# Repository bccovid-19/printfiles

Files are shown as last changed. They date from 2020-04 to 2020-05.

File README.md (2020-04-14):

# BC Covid-19 3D Printing Effort #

Hello,

If you are reading this it means you are thinking of helping the COVID-19 fight with your 3D printer. That's great! Please see more information below.

## How to start contributing? ##

The following questions are extracted from the [BC Covid-19 3D Printing Effort Starting Guide](https://docs.google.com/document/d/1Ttu-DrwoGttRoviB6C2idflY3-9sC5mBmkxYlhFMHls/edit?usp=sharing). This file is being kept up-to-date by our community and you will find the latest information there.

## Who's organizing all this? ##

Currently we are getting organized using the [BC Covid-19 3D Printing Slack channel](https://join.slack.com/t/bccovid-19/shared_invite/zt-cz01ettu-XZs6dWzob92pDKfFyCusag). There you can find the latest information on our efforts.

## How can I help? ##

- First you should sign up as a supplier using this [form](https://sites.google.com/view/gvrd-face-shield-printers/home/headset-printers).
- Check the demand for the items [here](https://sites.google.com/view/gvrd-face-shield-printers/home/total-supply-and-demand?authuser=0).
- Download the `.stl` files in this repo. Those are the files being used by our community.

## Is there a specific item in high demand? ##

Both [Visor Frames](https://github.com/bccovid-19/printfiles/tree/master/3DV%20Visor%20Frame) and [Ear Savers](https://github.com/bccovid-19/printfiles/tree/master/Ear%20Saver) are needed. You can check the current demand for the items [here](https://sites.google.com/view/gvrd-face-shield-printers/home/total-supply-and-demand?authuser=0).

## What 3D printers are required, known to work, or recommended? ##

Visor frames measure 159x193mm so printers must have plates large enough. If your build plate is too small, you may still be able to contribute with the Ear Savers. Beyond this any FDM printer should work.

## Am I required to print with a specific filament type? ##

- For both visor frames and ear savers, *PETG is preferred but PLA is acceptable.*

## Are there any specific slicing configurations needed (layer height, printing speed, etc.)? ##

Please take some time to read [this guide](https://3dverkstan.se/protective-visor/protective-visor-print-guide/), since it has some good information that can even speed up the printing time. Also see the Readme for each model.

## I have a few items printed, what now? ##

Delivery is likely to be handled by a local company, as will most pick-ups (more details expected by April 1st, 2020). We'll ask that each producer withhold the items they've printed for collection when there's a decent amount available, rather than a few at a time.

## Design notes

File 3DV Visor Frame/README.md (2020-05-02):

# 3DV Visor Frames

Please see http://faceshield.nu for information.
- [Print Settings Guide](https://3dverkstan.se/protective-visor/protective-visor-print-guide/)
- [Packaging & Handling](http://translate.google.com/translate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), specific to Sweden, but useful nonetheless.

# Common/Recommended Print Settings (See Print Settings Guide above for further details)
- Material: PETG, PLA acceptable if no other choice
- Nozzle: 0.4 mm (most common) to 1.0 mm
- Extrusion Width (0.4 mm to 0.6 mm nozzle, preferred): 0.72 mm
- Extrusion Width (0.4 mm to 0.6 mm nozzle, alternate): 0.70 mm, or see the guide.
- Extrusion Width (0.8 mm to 1.0 mm nozzle): 1.0 mm
- Layer Height: ~0.3 mm
- Infill: 0%, or increase to 100% if nubs have holes in them
- Walls: 3-4, goal is to have solid fill, i.e. the arms should be only filled with perimeters
- Support: No (N/A)
- Note that these are relatively aggressive print settings, may not work with all printers and will likely require finetuning. Your hotend's maximum volumetric flow (a factor of your extrusion width, layer height, and print speed) will likely determine how fast you can print each visor frame. For most printers, between 9-25 minutes/frame is very reasonable. You may need to run your extruder temperature hotter than normal to maintain good flow.
- For anyone new to printing PETG, main points to remember compared to PLA, it needs a hotter extruder temperature (220-260C), hotter build plate (70-100C), and is prone to stringing. Consider enabling "Combing" (print head avoids crossing perimeters) or equivalent, and especially with bowden setups, pay attention to retraction distance, retraction speed, and travel speed.

# File Selection
The [Extended Visor](./bcc3d_extended_v5.stl) version is preferred due to the increased forehead clearance and comfort. If your build plate cannot fit this model, then the standard [0.6mm Version](./Visor_Frame_NORTH_AMERICA_letter_6-hole_v5-0.6mm_chamferred.stl) and  [1mm Version](./Visor_Frame_NORTH_AMERICA_letter_6-hole_v5-1mm_chamferred.stl) are acceptable.

# Standard Visor
The [0.6mm Version](./Visor_Frame_NORTH_AMERICA_letter_6-hole_v5-0.6mm_chamferred.stl) should be tried first, as it has a reduced print time. If this version adheres too much to your print bed and is unable to be removed without damage please switch to the [1mm Version](./Visor_Frame_NORTH_AMERICA_letter_6-hole_v5-1mm_chamferred.stl).

# Extended Visor
The [Extended Visor](./bcc3d_extended_v5.stl) version can be used for practitioners needing an extended space between the visor and the face to accommodate glasses or goggles. It also increases the width of of the forehead contact surface and permits the use of padding (weatherstripping foam) if desired. It has been confirmed to work with the same dimensions and hole pattern as the standard version.

# Files for Prusa MK3 and MK3s

Within the `For Prusa MK3 and MK3s` folder you will find two .3mf files. These are print profiles of the [Extended Visor](./bcc3d_extended_v5.stl), with relatively aggressive settings for quick prints. One has had the bands flipped to spread the wear on the build platform a bit better.

# Credits

- 3D-Printed Protective Visor by 3DVerkstan/Erik Cederberg https://www.youmagine.com/designs/protective-visor-by-3dverkstan/
- 3D Printed Face Shield by by Retrolabs (remix of 3DVerkstan's model) https://retrolabs.com/3d-prints/3d-printed-face-shield-with-10-mil-pvc

# Changelog

### Version 5 - Extended:

- V5 provided by 3DVerskstan remixed with Retrolab's "Closed Top Padded" version

### Version 5:

- V5 provided by 3DVerskstan (improved joint between arms and forehead section, added separate file for 1 mm thick section)
- Chamfer added on the upper edges

### Version 3.3:

- Remixed to add chamfer on the upper edges

### Version 3:

- Original North America 6-hole version provided by 3DVerkstan

# License
This remix is created under [Creative Commons Attribution Share Alike](https://creativecommons.org/licenses/by-sa/3.0/deed.en_US)
- Commercial use is allowed, you must attribute the creator, you may remix this work and the remixed work should be made available under this license.

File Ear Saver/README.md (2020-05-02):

# ES.V4: ear_saver_small_V004.STL

## Recommended print settings

- Material: *PETG is preferred, PLA is acceptable*
- Nozzle: 0.4 mm to 1.0 mm
- Extrusion width (0.4 mm to 0.6 mm nozzle, preferred): 0.72 mm
- Extrusion width (0.4 mm to 0.6 mm nozzle, alternate): any divisor of 3.5 mm (eg. 0.5 mm, 0.583 mm, 0.7 mm, 0.875 mm)
- Extrusion width (0.8 mm to 1.0 mm nozzle): 1.44 mm
- Initial layer height: !!! This must be 0.3 mm
- Layer height: !!! This must be 0.3 mm
- Infill: N/A - Thin enough that it should print solid
- Walls: 3-4 for extrusion width of 0.72 mm; 2-3 for extrusion width of 1.44 mm; 5 for thinner extrusion widths
- Support: No (N/A)
- Note that these are relatively aggressive print settings, may not work with all printers and will likely require finetuning. Your hotend's maximum volumetric flow (a factor of your extrusion width, layer height, and print speed) will likely determine how fast you can print each ear saver. For most printers, between 3-10 minutes/ear saver is very reasonable. You may need to run your extruder temperature hotter than normal to maintain good flow.
- For anyone new to printing PETG, main points to remember compared to PLA, it needs a hotter extruder temperature (220-260C), hotter build plate (70-100C), and is prone to stringing. Consider enabling "Combing" (print head avoids crossing perimeters) or equivalent, and especially with bowden setups, pay attention to retraction distance, retraction speed, and travel speed.

## Documentation
[Google Document Link](https://docs.google.com/document/d/15-V81oS8I5RemRSrTbresdDm_2dw-AZuGhGRkiqIBxc)

## Credits

- Surgical mask strap by marslam on Thingiverse: https://www.thingiverse.com/thing:4202906
- surgical_mask_strap_small - Remix v03 for small beds by Crowshank on Thingiverse: https://www.thingiverse.com/thing:4246836
- Covid Surgical Mask Strap (ear_saver_small_V004) on Thingiverse: https://www.thingiverse.com/thing:4251451

## Changelog

### Version 4:

- Optimized layer and tool-path, prints with 0.3 mm layer height and 0.72 mm line width
- Added ergonomic centre design, reduced total material usage
- Changed angle of hooks for less tangling in hair, and better mask retention
- Reduced overall height to improve nesting
- Added step-over to improve layer bonding and create a rounded surface for handling

### Version 3:

- Overall length reduced to fit on smaller print beds
- Hook shape adjusted to improve printability
- Overall height scaled to reduce thickness of strap and hooks (improved flexibility and reduced print time)

## License
CC-BY 4.0 https://creativecommons.org/licenses/by/4.0/

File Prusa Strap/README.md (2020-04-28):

# Strap for Prusa RC3 Visor Frame and variants
This is a strap remix for the Prusa RC3 visor frame and BCC3D injection molded visor frame. Intended to be used with PETG only. Print this model only if requested.

## Details
- Material: PETG
- Extrusion/Line Width: 0.5 mm
- Layer Height: 0.2 mm

## Credits
- TPU Strap for the Prusa Protective Shield by Neil-Seattle https://www.prusaprinters.org/prints/27615-tpu-strap-for-the-prusa-protective-shield
- PETG Strap for the Prusa Protective Shield by Mike B https://www.prusaprinters.org/prints/28667-petg-strap-for-the-prusa-protective-shield

## License
This remix is created under [Attribution-ShareAlike 4.0 International (CC BY-SA 4.0)](https://creativecommons.org/licenses/by-sa/4.0/)

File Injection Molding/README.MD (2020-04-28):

# Injection Molded Frames

These are a near-complete version of what is being used by BC Covid-19 3D Printing Group for injection molding of a modified Prusa Face Shield. This mold was developed by [Cypress Solutions](http://www.cypress.bc.ca/), one of our generous sponsors, incorporating feedback from BC Covid-19.

Cypress Logo

# Credits
Prusa Face Shield by Prusa Research https://www.prusaprinters.org/prints/25857

# License
This remix is created under [Attribution-NonCommercial 4.0 International (CC BY-NC 4.0)](https://creativecommons.org/licenses/by-nc/4.0/)

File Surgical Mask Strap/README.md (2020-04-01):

# MS.V3: surgical_mask_strap_small_V003_Z60%_Single

## Recommended print settings
 - Material: PLA
 - Nozzle: 0.4 mm
 - Quality: Draft (0.3 - 0.35 mm)
 - Infill: N/A - Thin enough that it should print solid
 - Walls: 2
 - Support: No (N/A)

## Documentation
[Google Document Link](https://docs.google.com/document/d/15-V81oS8I5RemRSrTbresdDm_2dw-AZuGhGRkiqIBxc)

## Credits

 - Surgical mask strap by marslam on Thingiverse: https://www.thingiverse.com/thing:4202906
 - surgical_mask_strap_small - Remix v03 for small beds by Crowshank on Thingiverse: https://www.thingiverse.com/thing:4246836

## Changes

 - overall length reduced to fit on smaller print beds
 - hook shape adjusted to improve printability
 - overall height scaled to reduced thickness of strap and hooks (improved flexibility and reduced print time)

## License
CC-BY 4.0 https://creativecommons.org/licenses/by/4.0/

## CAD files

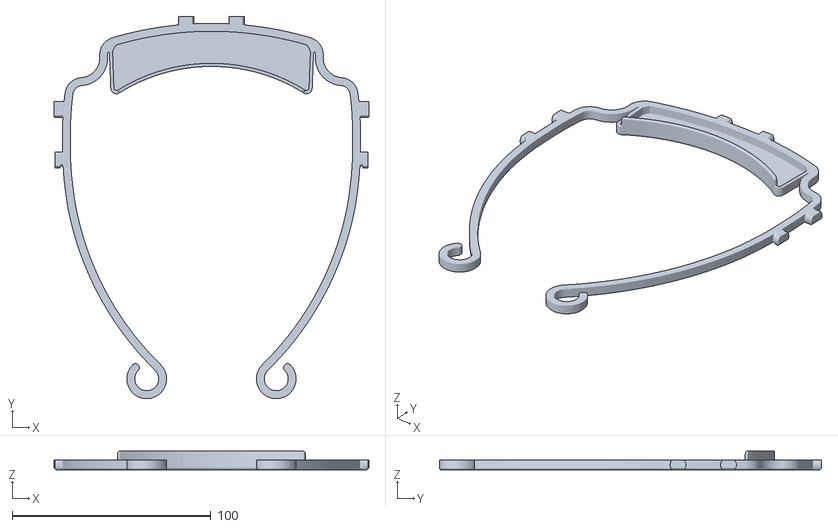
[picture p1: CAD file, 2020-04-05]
3DV Visor Frame/bcc3d_extended_v5.stl
158.5 x 192.4 x 9.56

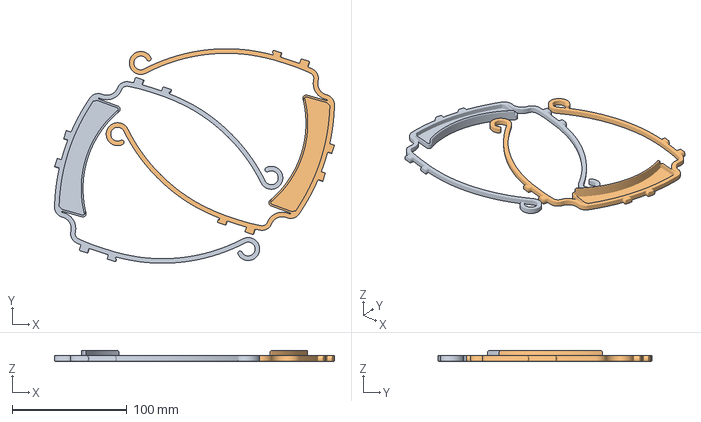
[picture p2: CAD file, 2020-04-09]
3DV Visor Frame/For Prusa i3 MK3 and MK3s/3DVerkstan_RetroLabs_v5_padded_NA_6hole_x2.3mf
243.7 x 186.6 x 9.56 mm
3DVerkstan_RetroLabs_v5_padded_NA_6hole.stl x 2

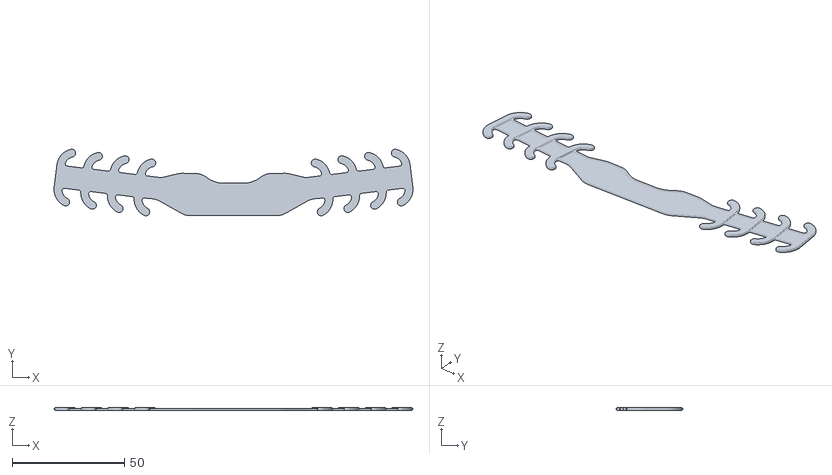
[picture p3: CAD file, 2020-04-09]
Ear Saver/ear_saver_small_V004.STL
160.2 x 29.7 x 1.20

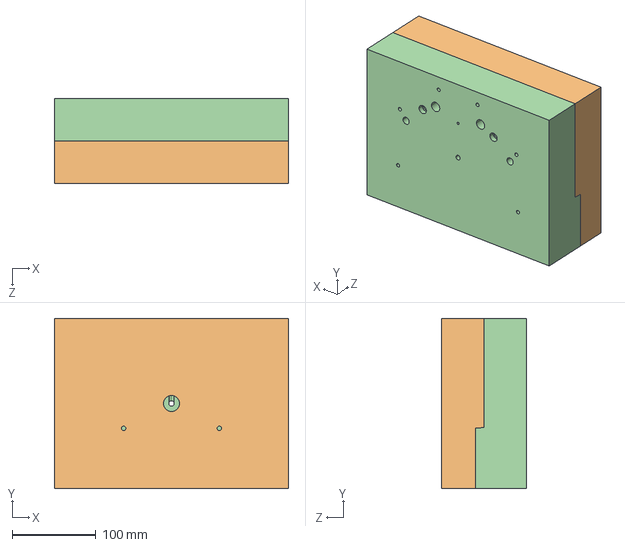
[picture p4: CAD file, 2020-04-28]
Injection Molding/cypress_face_shield_frame-v3.STEP
279.4 x 203.2 x 101.6 mm

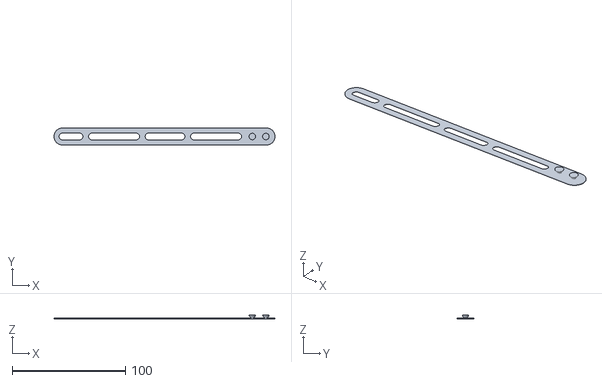
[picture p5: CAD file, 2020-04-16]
Prusa Strap/BCC3D_PETG_Prusa_Strap.4-pin.stl
195.0 x 15.0 x 3.49

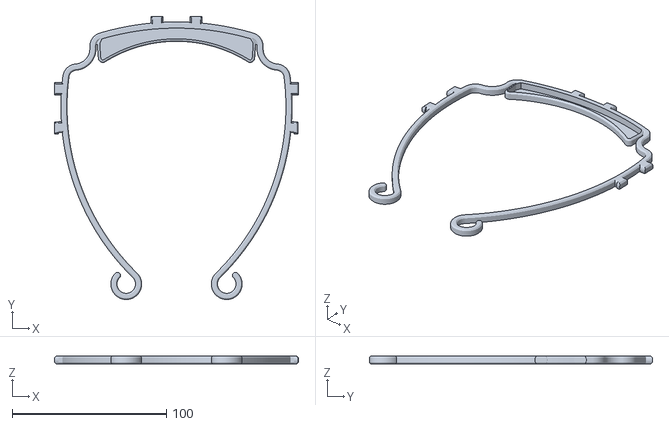
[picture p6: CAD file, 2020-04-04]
3DV Visor Frame/Visor_Frame_NORTH_AMERICA_letter_6-hole_v5-0.6mm_chamferred.stl
158.5 x 183.6 x 5.00

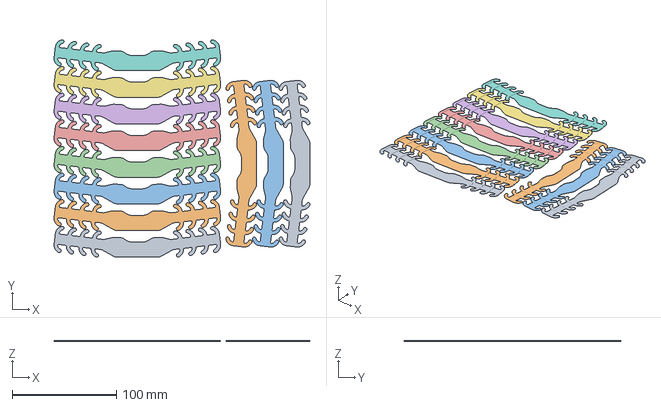
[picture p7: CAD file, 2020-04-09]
Ear Saver/ear_saver_small_V004_11x_prusa_PETG.3mf
245.9 x 208.9 x 1.20 mm

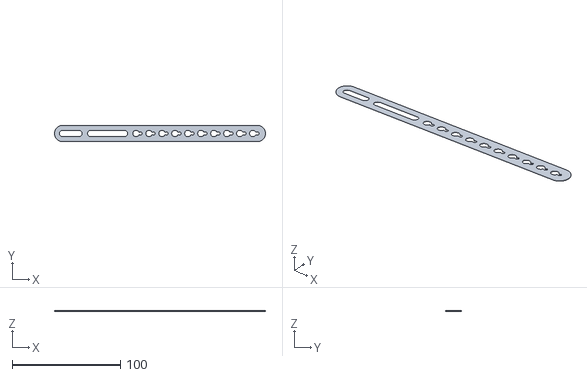
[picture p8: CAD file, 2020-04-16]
Prusa Strap/BCC3D_PETG_Prusa_Strap.4-hole.stl
195.0 x 15.0 x 0.8

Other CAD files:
3DV Visor Frame/For Prusa i3 MK3 and MK3s/3DVerkstan_RetroLabs_v5_padded_NA_6hole_x2 (flipped).3mf
3DV Visor Frame/Visor_Frame_NORTH_AMERICA_letter_6-hole_v5-1mm_chamferred.stl
Injection Molding/cypress_face_shield_frame-v3.x_t

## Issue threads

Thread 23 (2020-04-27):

The Slack Invite Link has expired

linderr, 2020-04-27:
Hi! My name is Linda and I am from www.findthemasks.ca
I spoke on the phone with Petko to join the Slack group but your link has already expired on both your main website as well as the README file on GitHub.

Please share or update a Slack link - thank you!

dan-bcc3d, 2020-04-28:
Hi linderr,

This has been fixed in https://github.com/bccovid-19/track/commit/aeb433f5ef4bd49216f60c0f2c8a6f111b863b31

Regards,
Dan

Closed 2020-04-28.

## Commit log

2020-03-31 added 3dv north america visor frame
    [Visor_Frame_NORTH_AMERICA_letter_6-hole_v3.stl]
2020-03-31 added links to print & packaging guides
2020-03-31 replace 3dv visor with chamferred version
    [Visor_Frame_NORTH_AMERICA_LETTER_v3.3.stl, Visor_Frame_NORTH_AMERICA_letter_6-hole_v3.stl]
2020-04-01 added pruse rc3 face shield
    [covid19_headband_rc3_3dvnubsBCStandard.v.5.stl, covid19_headband_rc3_3dvnubsHexadic.v.5.stl]
2020-04-01 removed prusa design
    - as it's causing confusion about what to print
    [covid19_headband_rc3_3dvnubsBCStandard.v.5.stl, covid19_headband_rc3_3dvnubsHexadic.v.5.stl]
2020-04-04 Update to V5 chamferred version of files.
    [Visor_Frame_NORTH_AMERICA_letter_6-hole_v5-0.6mm_chamferred.stl, Visor_Frame_NORTH_AMERICA_letter_6-hole_v5-1mm_chamferred.stl]
2020-04-04 remove v3.3 files and update README
    [Visor_Frame_NORTH_AMERICA_LETTER_v3.3.stl]
2020-04-05 add extended headband and document
    [3DVerkstan_RetroLabs_v5_padded_NA_6hole.stl]
2020-04-08 Add Prusa MK3(s) 3mf files
    [3DVerkstan_RetroLabs_v5_padded_NA_6hole_x2 (flipped).3mf, 3DVerkstan_RetroLabs_v5_padded_NA_6hole_x2.3mf]
2020-04-09 Ear saver v4 (#13)
    * Updated Ear Saver to V4
    * Removed v3 ear saver
    * Update README.md
    [ear_saver_small_V004.STL, ear_saver_small_V004_10x_prusa.3mf, surgical_mask_strap_small_V003_Z60%_Single.stl]
2020-04-09 Update README.md (#16)
    * Delete 3DVerkstan_RetroLabs_v5_padded_NA_6hole.stl
    * Rename to match readme
    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
    [bcc3d_extended_v5.stl]
2020-04-14 Update readmes and filenames for material clarification (#19)
    * Delete ear_saver_small_V004_10x_prusa.3mf
    * Ear Saver Prusa 3MF
    Rename to reflect x11
    * Delete ear_saver_small_V004_11x_prusa.3mf
    * Add files via upload
    Rename to reflect qty x11 and material
    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
    [ear_saver_small_V004_11x_prusa_PETG.3mf]
2020-04-16 Add PETG strap for injection molded frame (#20)
    * Create Readme.md
    * Add Prusa Strap for PETG
    * Update and rename Readme.md to README.md
    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
    [BCC3D_PETG_Prusa_Strap.4-hole.stl, BCC3D_PETG_Prusa_Strap.4-pin.stl]
2020-04-28 Add mold for injection molding (#22)
    * Create README.MD
    * Update README.MD
    * Update README.MD
    * Update README.MD
    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
    [cypress_face_shield_frame-v3.STEP, cypress_face_shield_frame-v3.x_t]
2020-05-02 Update print settings (#24)
